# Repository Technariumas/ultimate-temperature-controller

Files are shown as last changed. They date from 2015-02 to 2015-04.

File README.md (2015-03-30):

# The Ultimate temperature controller
I've built a bunch of various temperature controllers and temperature sensor interfaces over the years. This one is to end the suffering. 

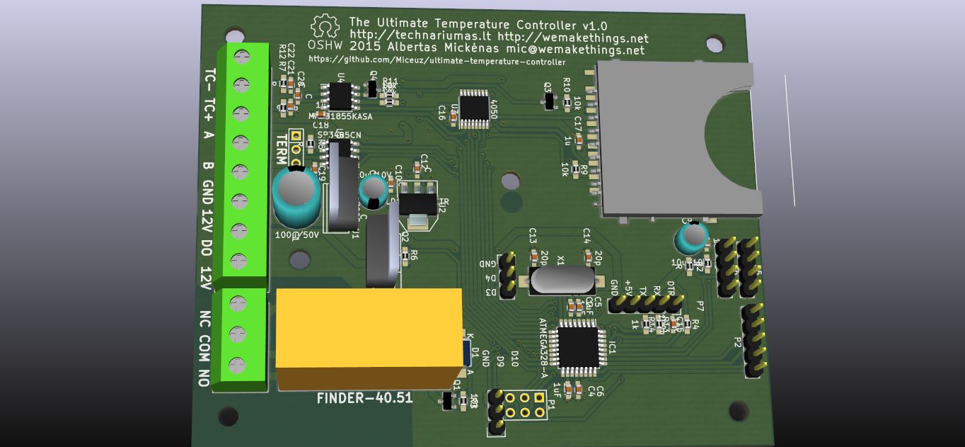
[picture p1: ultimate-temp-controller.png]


Features:
 * Arduino compatible
 * Thermocouple input via MAX31855
 * Output to LCD via I2C interface
 * Relay output
 * Open collector output
 * RS485 interface 
 * 4 key keypad interface
 * SD card

The device can act as a standalone controller or as a slave / master on RS485 network. 

## Standalone operation

Standalone controller is equiped with a LCD screen, a keypad and a SD card. Files containing temperature profiles can be stored on the SD card. A profile can be selected using the menu system via keypad and LCD interface. PID controller runs on the microcontroller and ensures the precise temperature control.

Power is controlled with a solid state relay. Open collector output is used to turn the SSR on and off. Alternatively an on-board mechanical relay can be used for power controll. 

Controller is powered by internal low power 12V SMPS.

## Slave operation

In slave mode no keypad and SD card is available, controller can be equiped with a more robust 7 segment LED screen for temperature readout. The slave controller sits on a RS485 network and listens for temperature commands from the master controller.

Slave has the same power output options as in standalone mode. 12V supply for the slave can be supplied by either a local SMPS or via UTP cable from the master. 

## Master operation

In case of master operation the master controller scans RS485 network for slaves. SD card is used to store temperature profiles. A profile can be selected via LCD/keypad interface for each of the slaves available on the RS485 network.

Master is not equiped with power switching options, but can provide 12V to slaves.

# The first prototype board

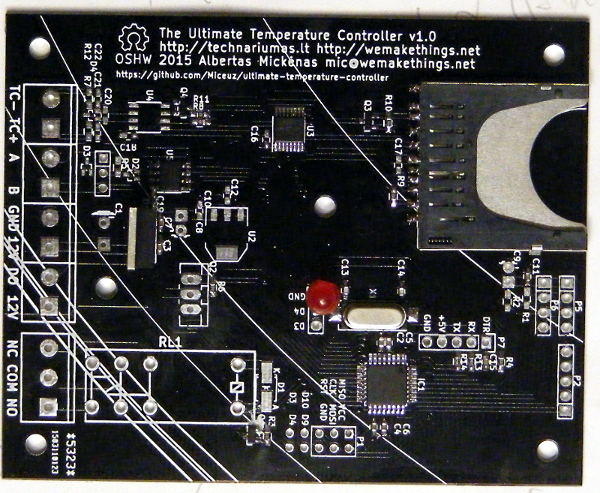
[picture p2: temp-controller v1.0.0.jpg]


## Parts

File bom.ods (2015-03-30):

Id | Designator | Package | Quantity | Designation | Available
4 | U3 | TSSOP-16_4.4x5mm_Pitch0.65mm | 1 | 4050 | X
6 | Q4,Q1,Q3 | sot23 | 3 | MOS_N | X
7 | C1 | Capacitor8x13RM3.8 | 1 | 100u/50V
8 | C2,C4,C5,C6 | C_0603_HandSoldering | 4 | 1uF | X
9 | C3,C7,C10,C12,C19,C20,C21,C22 | C_0603_HandSoldering | 8 | C | X
10 | C8,C9 | Capacitor5x6RM2.5 | 2 | 10u/10V
11 | C11,C16,C17,C18 | C_0603_HandSoldering | 4 | 1u | X
12 | C13,C14 | C_0603_HandSoldering | 2 | 20p | X
13 | D1 | Diode-SMA_Handsoldering | 1 | DIODE
14 | IC1 | TQFP-32_7x7mm_Pitch0.8mm | 1 | ATMEGA328-A | X
22 | Q2 | TO-220_FET-GDS_Vertical_LargePads | 1 | MOS_N
23 | R1,R2,R5,R7,R12 | R_0603_HandSoldering | 5 | R | X
24 | R3,R4,R6,R8,R9,R10,R11 | R_0603_HandSoldering | 7 | 10k | X
25 | U2 | SOT-223 | 1 | LD1117S12CTR | X
26 | U4 | SOIC-8_3.9x4.9mm_Pitch1.27mm | 1 | MAX31855KASA
27 | U5 | SOIC-8_3.9x4.9mm_Pitch1.27mm | 1 | SP3485CN | X
28 | X1 | Crystal_HC49-SD_SMD | 1 | CRYSTAL | X
30 | P4 | mors_2p | 1 | POWER
31 | U1 | LM78XXV | 1 | 7805 | X
32 | RL1 | relay_40.61 | 1 | FINDER-40.51
35 | R13,R14 | R_0603_HandSoldering | 2 | 1k | X
36 | C15 | C_0603_HandSoldering | 1 | 100n | X
38 | D2,D3,D4 | SOT-323 | 3 | TVS-DUAL | X

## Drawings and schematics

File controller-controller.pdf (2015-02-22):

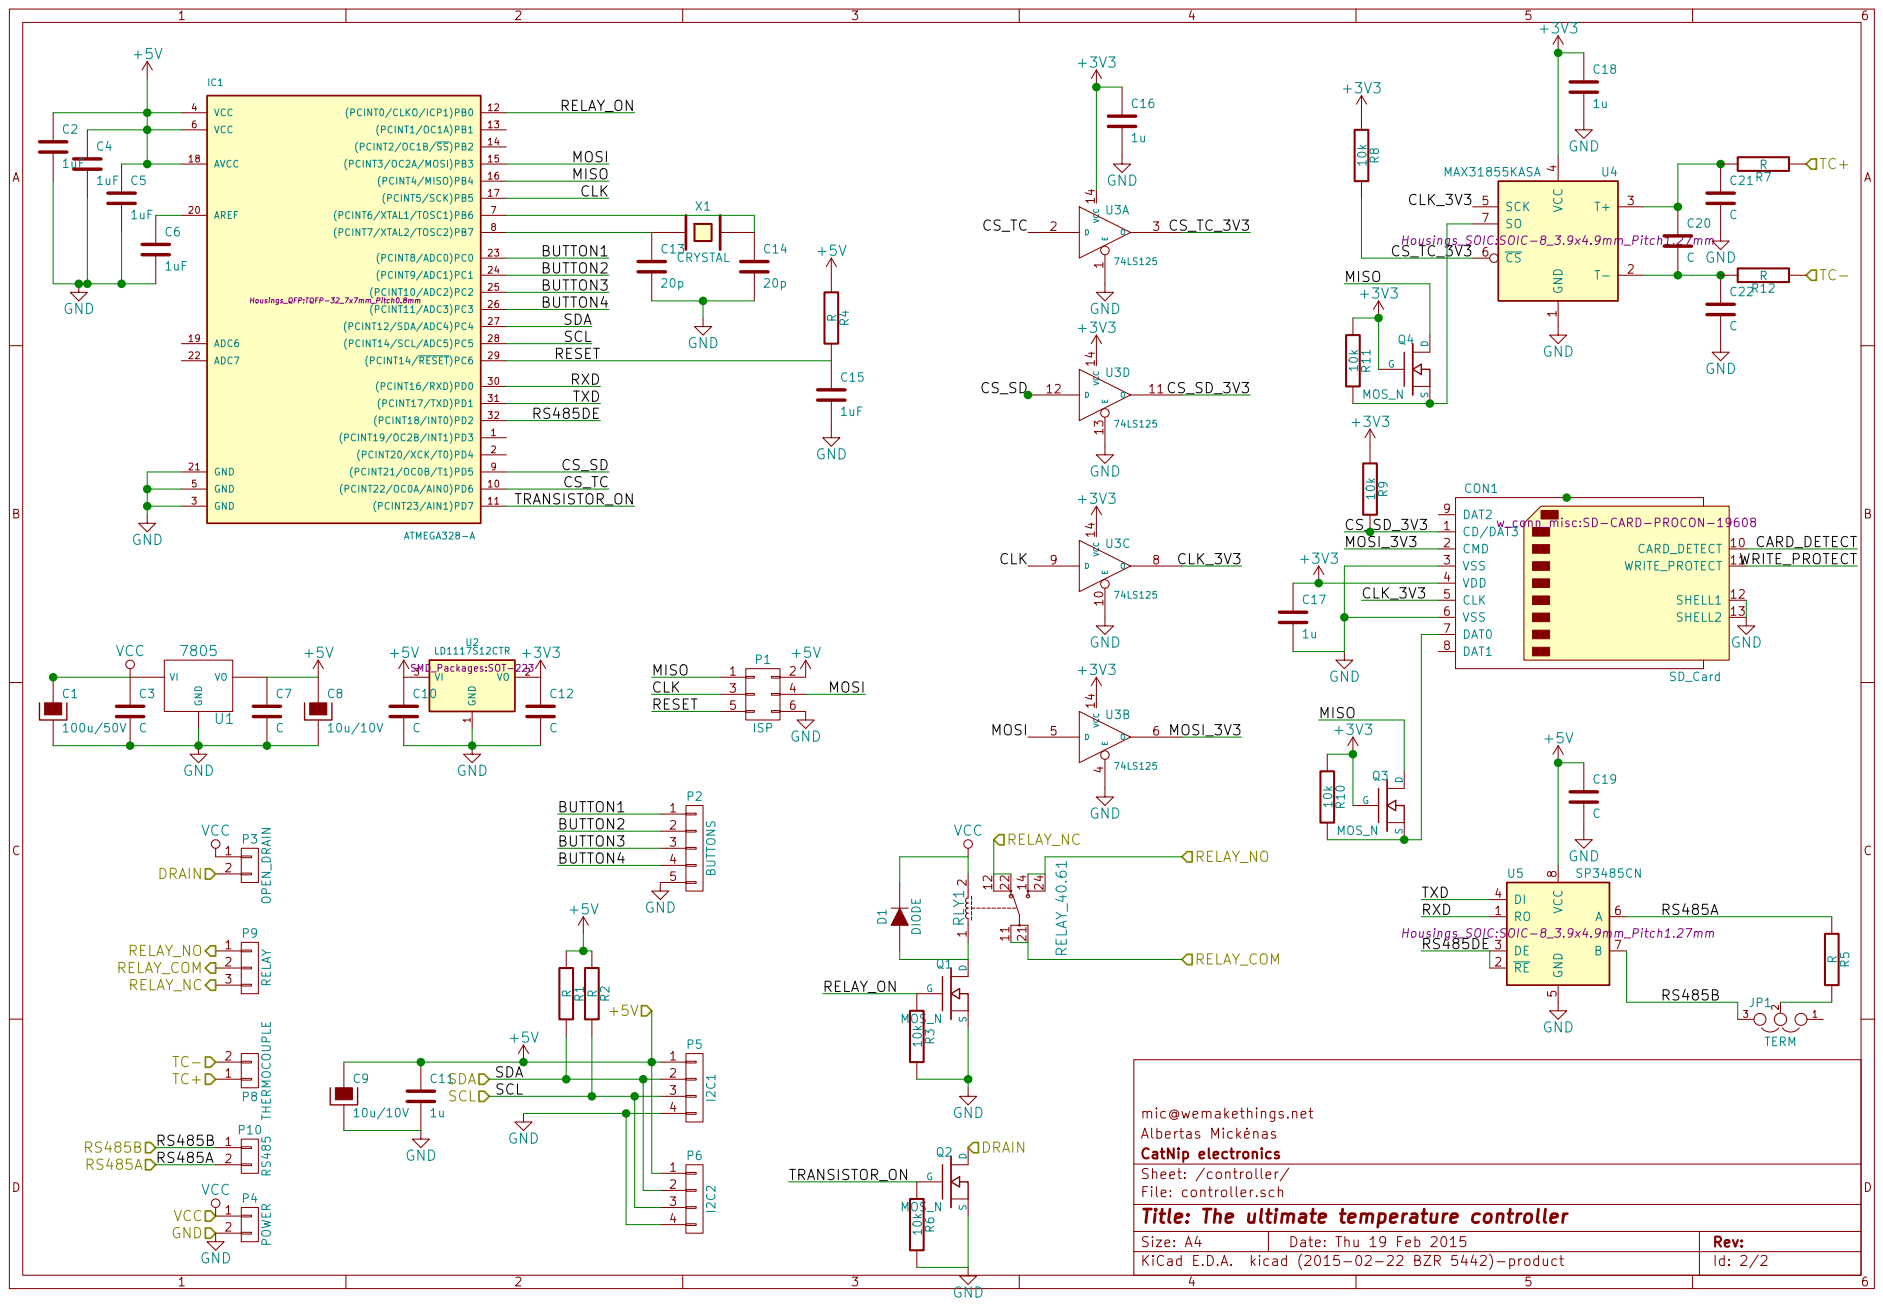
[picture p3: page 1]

4 SCK 5 CS 6 SO 7 MAX31855KASA U4 Housings_SOIC:SOIC-8_3.9x4.9mm_Pitch1.27mm
CLK_3V3

Id: 2/2 Title: The ultimate temperature controller File: controller.sch Sheet: /controller/ CatNip electronics Albertas Micknas mic@wemakethings.net

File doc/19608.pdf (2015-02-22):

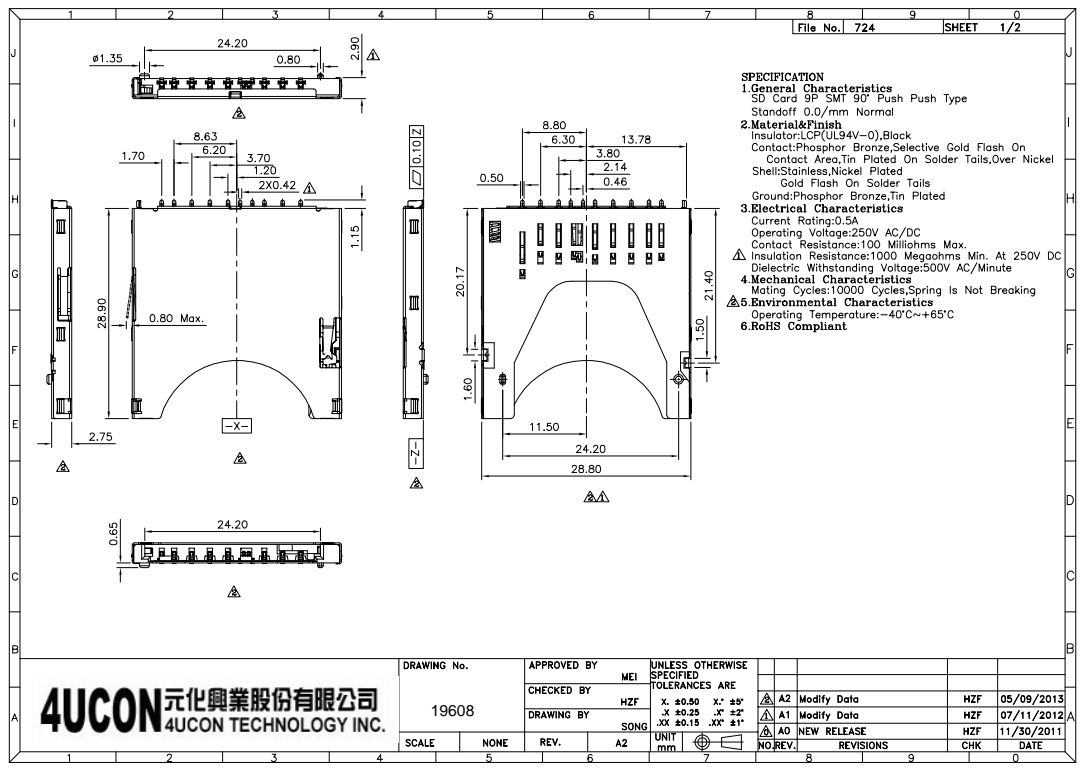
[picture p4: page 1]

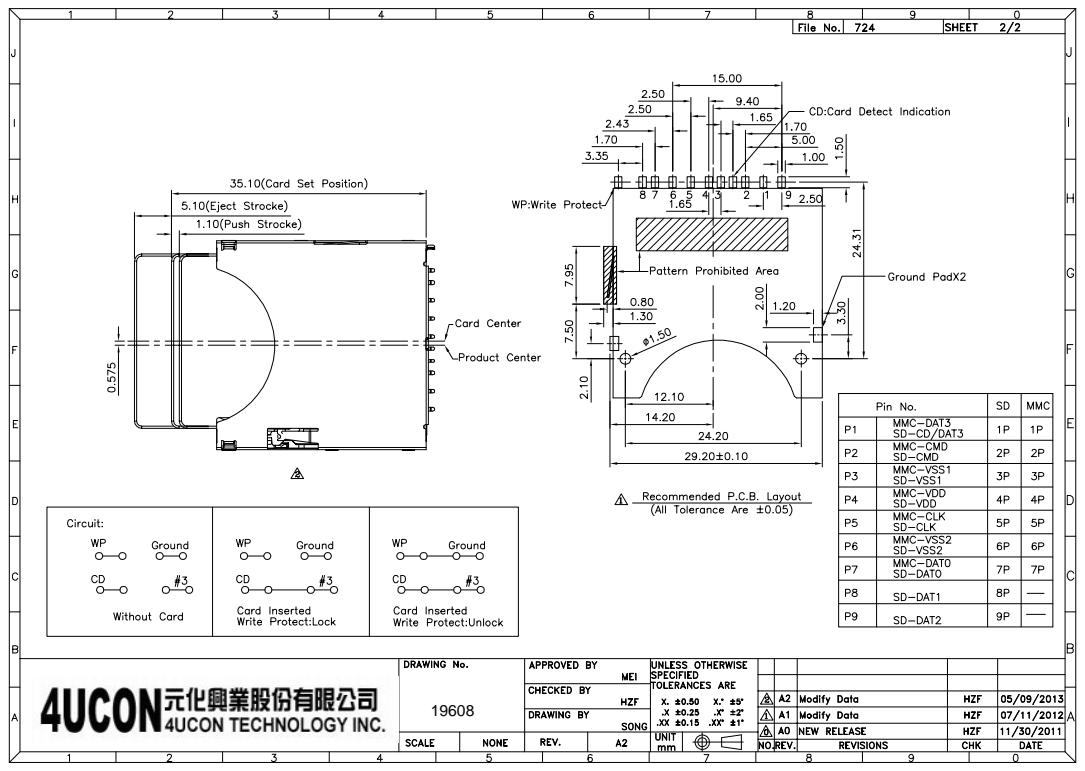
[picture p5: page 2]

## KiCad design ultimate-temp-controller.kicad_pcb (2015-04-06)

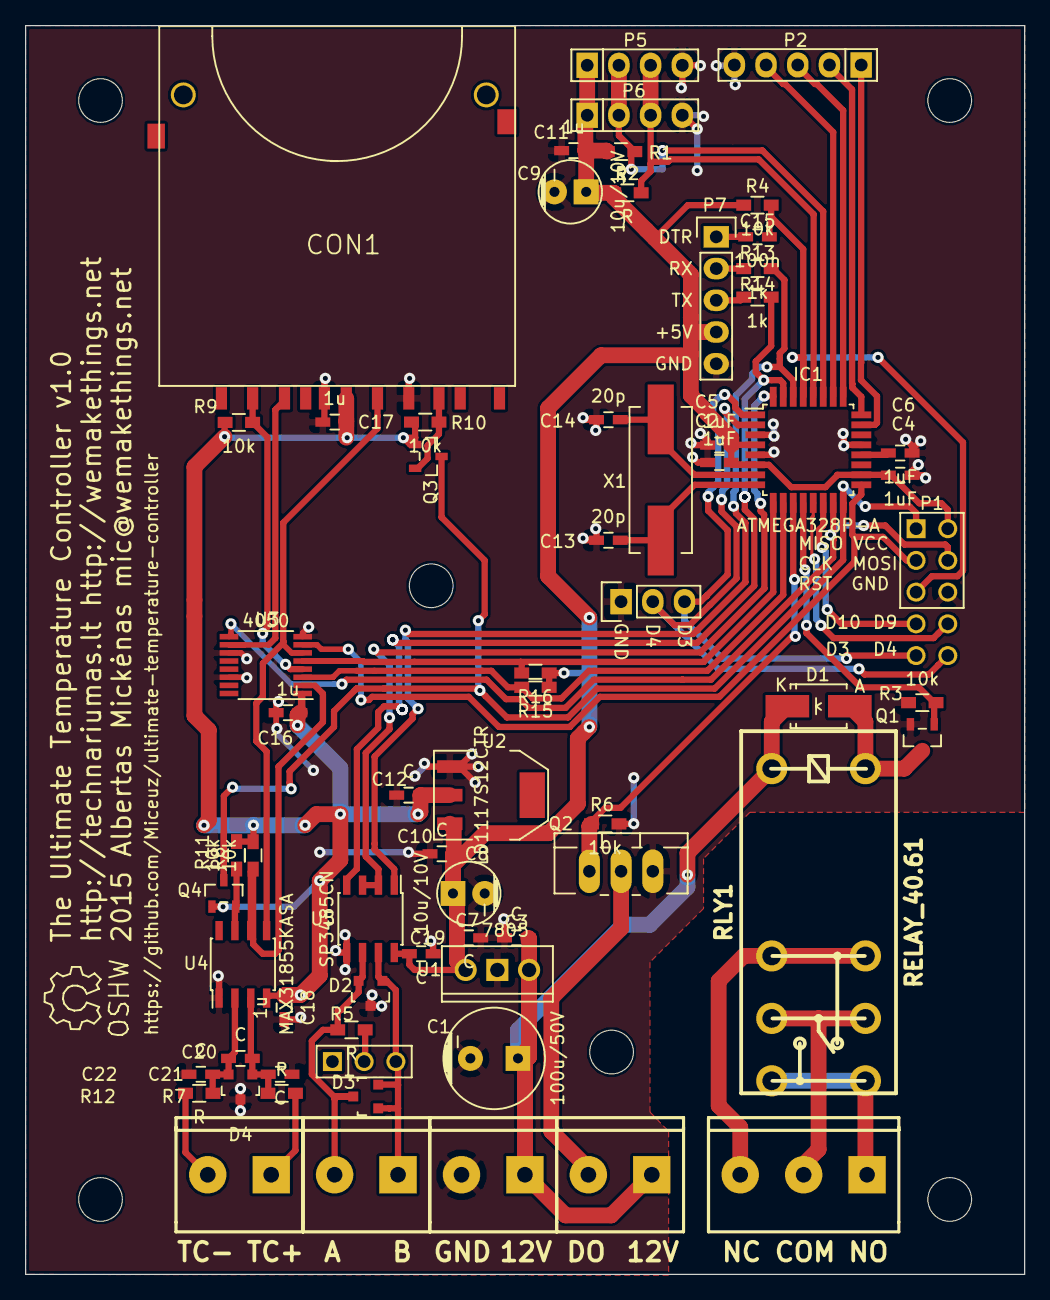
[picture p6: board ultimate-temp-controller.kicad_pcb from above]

Board: 2 copper layers, 80.0 x 100.0 mm, 76 parts (0 on the bottom side), 49 nets.

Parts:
C1: 100u/50V; Capacitor8x13RM3.8
C2, C4, C5, C6: 1uF; C_0603_HandSoldering
C3, C7, C10, C12, C19, C20, C21, C22: C; C_0603_HandSoldering
C8, C9: 10u/10V; Capacitor5x6RM2.5
C11, C16, C17, C18: 1u; C_0603_HandSoldering
C13, C14: 20p; C_0603_HandSoldering
C15: 100n; C_0603_HandSoldering
CON1: SD_Card; SD-CARD-PROCON-19608
D1: DIODE; Diode-SMA_Handsoldering
D2, D3, D4: TVS-DUAL; SOT-23
IC1: ATMEGA328P-A; TQFP-32_7x7mm_Pitch0.8mm
JP1: TERM; pin_array_1x03
MountingHole_3-5mm, MountingHole_3-5mm#2, MountingHole_3-5mm#3, MountingHole_3-5mm#4, MountingHole_3-5mm#5, MountingHole_3-5mm#6: VAL**; MountingHole_3-5mm
P1: ISP; pin_array_2x03
P2: BUTTONS; Pin_Header_Straight_1x05
P3: OPEN_DRAIN; mors_2p
P4: POWER; mors_2p
P5: I2C1; Pin_Header_Straight_1x04
P6: I2C2; Pin_Header_Straight_1x04
P7: CONN_01X05; Pin_Header_Straight_1x05
P8: THERMOCOUPLE; mors_2p
P9: RELAY; mors_3p
P10: RS485; mors_2p
Pin_Header_Straight_1x02, Pin_Header_Straight_1x02#2: VAL**; Pin_Header_Straight_1x02
Pin_Header_Straight_1x03: VAL**; Pin_Header_Straight_1x03
Q1, Q3, Q4: MOS_N; sot23
Q2: MOS_N; TO-220_FET-GDS_Vertical_LargePads
R1, R2, R5, R7, R12: R; R_0603_HandSoldering
R3, R4, R6, R8, R9, R10, R11, R15, R16: 10k; R_0603_HandSoldering
R13, R14: 1k; R_0603_HandSoldering
RLY1: RELAY_40.61; relay_40.61
Symbol_OSHW-Logo_SilkScreen: VAL**; Symbol_OSHW-Logo_SilkScreen
U1: 7805; LM78XXV
U2: LD1117S12CTR; SOT-223
U3: 4050; TSSOP-16_4.4x5mm_Pitch0.65mm
U4: MAX31855KASA; SOIC-8_3.9x4.9mm_Pitch1.27mm
U5: SP3485CN; SOIC-8_3.9x4.9mm_Pitch1.27mm
X1: CRYSTAL; Crystal_HC49-SD_SMD

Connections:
+3V3: C12.1, C16.1, C17.1, C18.1, CON1.4, Q3.G, Q4.G, R8.1, R9.1, R10.1, R11.1, U2.2, U3.1, U4.4
+5V: C2.1, C4.1, C5.1, C7.1, C8.1, C9.1, C10.1, C11.1, C19.1, IC1.4, IC1.6, IC1.18, P1.2, P5.1, P6.1, P7.4, R1.1, R2.1, R4.1, R15.1, R16.1, U1.VO, U2.3, U5.8
+12V: C1.1, C3.1, D1.2, P3.1, P4.1, RLY1.2, U1.VI
/controller/BUTTON1: IC1.23, P2.1
/controller/BUTTON2: IC1.24, P2.2
/controller/BUTTON3: IC1.25, P2.3
/controller/BUTTON4: IC1.26, P2.4
/controller/CLK: IC1.17, P1.3, U3.7
/controller/CLK_3V3: CON1.5, U3.6, U4.5
/controller/CS_SD: IC1.9, R16.2, U3.5
/controller/CS_SD_3V3: CON1.1, R9.2, U3.4
/controller/CS_TC: IC1.10, R15.2, U3.3
/controller/CS_TC_3V3: R8.2, U3.2, U4.6
/controller/DRAIN: P3.2, Q2.D
/controller/DTR: C15.1, P7.1
/controller/MISO: IC1.16, P1.1, Q3.D, Q4.D
/controller/MOSI: IC1.15, P1.4, U3.9
/controller/MOSI_3V3: CON1.2, U3.10
/controller/RELAY_COM: P9.2, RLY1.11, RLY1.21
/controller/RELAY_NC: P9.3, RLY1.12, RLY1.22
/controller/RELAY_NO: P9.1, RLY1.14, RLY1.24
/controller/RELAY_ON: IC1.12, Q1.G, R3.1
/controller/RESET: C15.2, IC1.29, P1.5, R4.2
/controller/RS485A: D2.2, D3.3, P10.2, R5.1, U5.6
/controller/RS485B: D2.1, D3.1, D3.2, JP1.3, P10.1, U5.7
/controller/RS485DE: IC1.32, U5.2, U5.3
/controller/RX: P7.2, R13.1
/controller/RXD: IC1.30, R13.2, U5.1
/controller/SCL: IC1.28, P5.3, P6.3, R2.2
/controller/SDA: IC1.27, P5.2, P6.2, R1.2
/controller/TC+: P8.1, R7.1
/controller/TC-: P8.2, R12.1
/controller/TRANSISTOR_ON: IC1.11, Q2.G, R6.1
/controller/TX: P7.3, R14.1
/controller/TXD: IC1.31, R14.2, U5.4
GND: C1.2, C2.2, C3.2, C4.2, C5.2, C6.2, C7.2, C8.2, C9.2, C10.2, C11.2, C12.2, C13.2, C14.2, C16.2, C17.2, C18.2, C19.2, C21.2, C22.2, CON1.3, CON1.6, D2.3, D4.3, IC1.3, IC1.5, IC1.21, P1.6, P2.5, P4.2, P5.4, P6.4, P7.5, Pin_Header_Straight_1x03.1, Q1.S, Q2.S, R3.2, R6.2, U1.GND, U2.1, U3.8, U3.11, U3.14, U4.1, U5.5
unnamed: C6.1, IC1.20
unnamed: C13.1, IC1.8, X1.1
unnamed: C14.1, IC1.7, X1.2
unnamed: C20.1, C21.1, D4.1, R7.2, U4.3
unnamed: C20.2, C22.1, D4.2, R12.2, U4.2
unnamed: CON1.7, Q3.S, R10.2
unnamed: D1.1, Q1.D, RLY1.1
unnamed: IC1.1, Pin_Header_Straight_1x02.1, Pin_Header_Straight_1x03.3
unnamed: IC1.2, Pin_Header_Straight_1x02.2, Pin_Header_Straight_1x03.2
unnamed: IC1.13, Pin_Header_Straight_1x02#2.2
unnamed: IC1.14, Pin_Header_Straight_1x02#2.1
unnamed: JP1.2, R5.2
unnamed: Q4.S, R11.2, U4.7

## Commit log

2015-02-19 Initial. Schematics is kinda ready
    [controller.sch, ultimate-temp-controller.sch]
2015-02-19 Add ISP header
    [controller.sch]
2015-02-19 Add annotations and netlist
    [controller.sch]
2015-02-19 Add SVG drawing of schematics
2015-02-19 Add open drain output, shuffle other connectors around
    [controller.sch, ultimate-temp-controller.sch]
2015-02-19 Shuffle stuff around, generate the new schematics svg
    [controller.sch]
2015-02-19 Add netlist, assign footprints and 3d models, fool around with placement a bit
    [controller.sch, ultimate-temp-controller.kicad_pcb]
2015-02-22 Add the correct relay footprint, solve MISO voltage level conversion, route the PCB
    [controller.sch, ultimate-temp-controller.kicad_pcb, ultimate-temp-controller.sch]
2015-02-22 Create the correct SD card slot footprint for cheap and popular ebay SD card slot
    [ultimate-temp-controller.kicad_pcb]
2015-02-22 Shorten the board, reroute
    [controller.sch, ultimate-temp-controller.kicad_pcb]
2015-02-22 Remove ground fill for high voltage areas
    [ultimate-temp-controller.kicad_pcb]
2015-02-22 Add schematics svg
2015-02-23 Add dimensions
    [ultimate-temp-controller.kicad_pcb]
2015-02-23 Put silkscreen to order
    [ultimate-temp-controller.kicad_pcb]
2015-02-23 Add a serial header for Arduino compatible programming
    [controller.sch, ultimate-temp-controller.kicad_pcb]
2015-02-23 Break out leftover pins
    [ultimate-temp-controller.kicad_pcb]
2015-02-24 Add some silkscreen
    [ultimate-temp-controller.kicad_pcb]
2015-02-26 Use 4050 as a level shifter
    [controller.sch, ultimate-temp-controller.kicad_pcb]
2015-02-27 Turn 4050 180 degrees, enjoy better routing, move spare pins near ISP header
    [ultimate-temp-controller.kicad_pcb]
2015-02-27 Add mounting hole for expansion header, add a hole near screw terminals for more support
    [ultimate-temp-controller.kicad_pcb]
2015-03-02 Add protection
    [controller.sch]
2015-03-02 Add protection devices ot the PCB
    [ultimate-temp-controller.kicad_pcb]
2015-03-02 Consolidate spare pins on the expansion header
    [ultimate-temp-controller.kicad_pcb]
2015-03-30 Add a board photo
2015-03-30 Add gerbers
    [ultimate-temp-controller-B_Cu.gbr, ultimate-temp-controller-B_Mask.gbr, ultimate-temp-controller-B_SilkS.gbr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]
2015-03-30 Add comments about fixes for the next revision
    [ultimate-temp-controller.kicad_pcb]
2015-03-30 Add bom list:
    [bom.ods]
2015-03-31 Fix schematics after kicad library upgrade
    [controller.sch]
2015-03-31 Add more comments about what to fix
    [ultimate-temp-controller.kicad_pcb]
2015-04-04 Fix SD card footprint by mirroring the pads
    [ultimate-temp-controller.kicad_pcb]
2015-04-04 Fix SD card footprint by mirroring mechanical solder pads
    [ultimate-temp-controller.kicad_pcb]
2015-04-04 Optimise some tracks
    [ultimate-temp-controller.kicad_pcb]
2015-04-05 Fix missing ground connection. Change the MCU to Atmega328P for better Arduino compatibility
    [controller.sch]
2015-04-05 Change TVS diode footprints to SOT-23
    [ultimate-temp-controller.kicad_pcb]
2015-04-05 Put netlist and fottprint assignments into order, but something went hugely wrong -- 3V3 net replaces VCC net. FML
    [controller.sch]
2015-04-05 Fix netlist problem - update custom tuded ICs: U3 power connections are visible, U5 pin ordering more convenient. Saved cymbol changes to the local cache, not clear if this will help thoug..
    [controller.sch, ultimate-temp-controller.kicad_pcb]
2015-04-05 Swap TVS pins again. Add pullup resistors to CS lines.
    [controller.sch, ultimate-temp-controller.kicad_pcb]
